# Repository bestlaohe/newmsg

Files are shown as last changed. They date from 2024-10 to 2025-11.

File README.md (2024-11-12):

+--------------------------------+
|                          |     |     <- 电量显示（右上角 16x8）
|                          |     |
|                          |     |
|                          |     |
|                          |     |
|                          |     |
|                          |     |
|       聊天窗口           |     |     <- 聊天窗口（中间 120x100）
|                          |     |
|                          |     |
|                          |     |
|                          |     |
|                          |     |
|                          |     |
|                          |     |
|                          |     |
|                          |     |
|--------------------------|     |
|         输入框           |     |     <- 输入框（底部 120x16）
+--------------------------------+

一格就是一圈来0,1区分正反转，

帮我用***来画一个128*128的tft彩屏的主界面的ui布局，这个界面右上角具有电量显示，中间是聊天窗口，最底下是输入框

聊天窗口交互:

滚轮上滚：切换字母
滚轮下滚：删除一个字母
短按按钮：确认输入的字母
按住并上滚：发送消息
按住并下滚：删除最后一条消息
长按按钮：切换到设置页面

设置页面交互:
滚轮上下滚动：切换设置选项
短按按钮：确认选择的设置
滚轮上下滚动：选择切换的档位
长按按钮：返回聊天窗口

亮度，震动模式，lora频率，发射功率定义，带宽表定义等，还有id设置，

聊天窗口的交互
按住且往上滚表示发送，按住且往下滚表示删除一个，滚动切换字母（一开始为空的），短按按键表示确认，

<!-- 长按按键切换软件交互窗口
聊天记录窗口的交互
滚动翻动聊天记录
按住且往下滚表示删除聊天记录
 -->

长按按键切换设置按钮，短按确认进入设置页面
滚动切换，短按确认，长按返回

限幅动作，找数据超出

休眠独立看门狗复位，按键无法唤醒
都是重新开机，然后看门狗是断开时钟，按键

低速时钟（LSI）
LSI 是系统内部约 128kHz 的 RC 振荡器产生的低速时钟信号。它可以在停机和待机模式下保持
运行，为 RTC 时钟、独立看门狗和唤醒单元提供时钟基准。进一步信息可参考数据手册的电气特性
部分。LSI 可以通过设置 RCC_RSTSCKR 寄存器中的 LSION 位被启动和关闭，然后通过查询 LSIRDY 位
检测 LSI RC 振荡是否稳定，硬件在

看门狗靠这个时钟，把他失能就不会看门狗复位了，现在是唤醒问题，唤醒不了

 4s喂狗，2s唤醒

喂狗必须在while1里面

        开机
        看门狗开
        自动唤醒开
        喂狗
        休眠needsleep==1
        自动唤醒喂狗
        休眠needsleep==1
        自动唤醒喂狗
        休眠needsleep==1
        自动唤醒喂狗
        休眠needsleep==1
        人工唤醒needsleep==0
        自动唤醒喂狗
        人工运行喂狗needsleep==0
        自动唤醒喂狗
        休眠needsleep==1

        while里面判断是否是自动唤醒的状态，是就喂狗，不是跑代码

        if(needsleep==1){
                喂狗+睡觉
        }
        else{
                喂狗+工作

        }

        只刷新一次
        删除信息页面内容

        画矩形太低效了

        聊天记录翻页

           需要验证这个有没有用 Delay_Ms(1);比较耗时3个地方都有

           为什么第一次休眠会乱码

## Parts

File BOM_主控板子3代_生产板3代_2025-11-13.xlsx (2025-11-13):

编号 | 数量 | 备注 | 位号 | 封装 | LCSC Price | LCSC Stock | JLCPCB Price | JLCPCB Stock
1 | 1 | CA-S01 | ANT1 | ANT-SMD_L15.0-W3.0 |  |  | 0.004 | 0 | 完成
2 | 4 | 100nF | C2,C58,C59,C60 | C0603 | 0.0152 | 601410 | 0.0152 | 89490924 | 完成 | 3.16
3 | 1 | 22uF | C4 | C0603 | 0.0575 | 476131 | 0.0575 | 10693591 | 完成 | 2.5
4 | 2 | 1uF | C5,C57 | C0603 | 0.0311 | 112269 | 0.0311 | 11906395 | 完成 | 2
6 | 1 | BAT60B | D8 | SOD-323_L1.7-W1.3-LS2.6-RD-1 | 0.1355 | 1412 | 0.136 | 29969 | 完成 | 5
7 | 1 | AFH34-S12FIA-1H | FPC1 | FPC-SMD_12P-P0.50_THD0509-12CL-GF | 0.8454 | 1512 | 0.845 | 7548 | 完成 | 5
10 | 2 | 1MΩ | R4,R5 | R0603 | 0.0067 | 71383 | 0.0067 | 8524241 | 完成 | 0.81
11 | 2 | 5.1kΩ | R58,R59 | R0603 | 0.0066 | 60036 | 0.0066 | 8171975 | 完成 | 0.81
12 | 1 | 2.2kΩ | R62 | R0603 | 0.0064 | 21609 | 0.0064 | 3307043 | 完成 | 0.81
13 | 1 | 30kΩ | R66 | R0603 | 0.0069 | 19073 | 0.0069 | 2428632 | 完成 | 0.81
14 | 1 | 10kΩ | R67 | R0603 | 0.0067 | 68799 | 0.0067 | 7440441 | 完成 | 0.81
16 | 1 | TM-2024A | SW4 | SW-SMD_TM-2024A | 2.665 | 1312 | 2.665 | 4043 | 完成 | 32.2
17 | 1 | MINI MSK12CO2 | SW5 | SW-SMD_MSK12CO2 | 1.0242 | 27346 | 1.0242 | 110085 | 完成 | 13.9
18 | 1 | CH32V003F4P6 | U1 | OLIMEX_IC-FP:TSSOP20_Pitch-0.65mm_6.6x4.5x1.2mm | 1.7718 | 1229 | 1.772 | 6902 | 完成 | 30
19 | 1 | ME6206A33M3G | U5 | SOT-23-3_L2.9-W1.6-P1.90-LS2.8-BR | 0.3322 | 835 | 0.332 | 9018 | 完成 | 8
20 | 1 | XL1278-SMT | U24 | SX1278 |  |  |  |  | 完成 | 319
21 | 1 | SS8050 | U25 | SOT-23-3_L2.9-W1.3-P1.90-LS2.4-BR | 0.0727 | 10857 | 0.0727 | 546075 | 完成 | 3
22 | 1 | CS-1254R-02 | U29 | CONN-SMD_2P-P1.00_CS-1254R-02 | 0.5538 | 148 | 0.554 | 745 | 完成 | 3.49
23 | 1 | TP4057-42-SOT26-R | U37 | SOT-23-6_L2.9-W1.6-P0.95-LS2.8-BL | 0.8671 | 4162 | 0.867 | 27867 | 完成 | 3.9
25 | 1 | HX TYPE-C 16PIN | USB2 | USB-C-SMD_TYPE-C16PIN | 0.4811 | 4681 | 0.481 | 16437 | 完成 | 7
 |  |  |  |  |  |  |  |  |  | 442.2

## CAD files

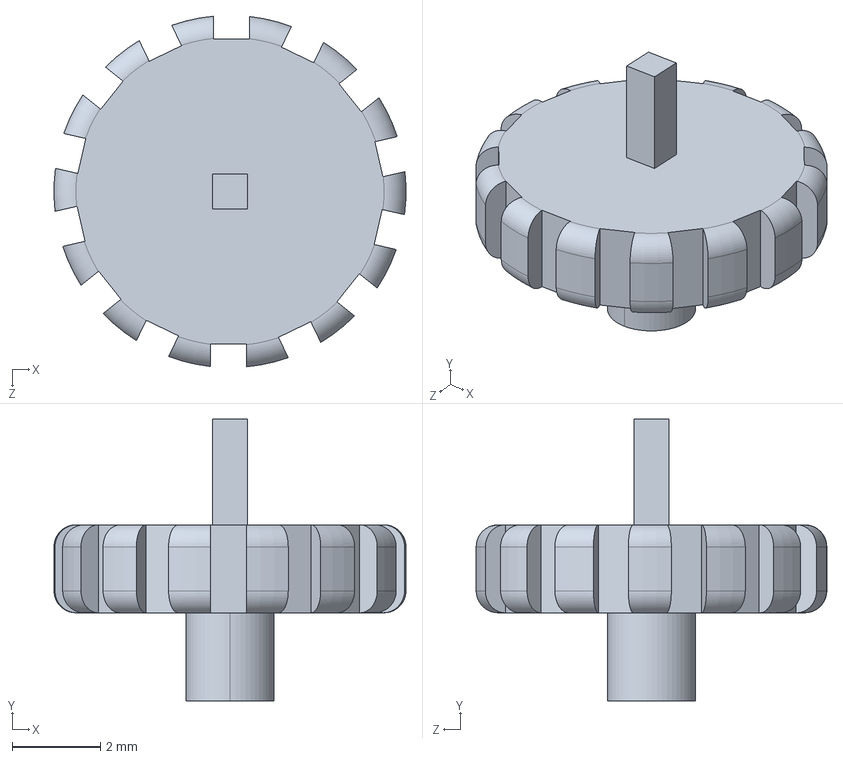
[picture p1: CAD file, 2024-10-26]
结构/滚轮.STEP
8.00 x 6.40 x 7.97 mm

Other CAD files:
结构/滚轮.SLDPRT

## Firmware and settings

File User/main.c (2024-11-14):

#include "debug.h"
#include "encode.h" // timeapp->encode->main
#include "adc.h"    // timeapp->pwm.screen->screen_api->adc->main
#include "SX1278.h" // gpio->SX1278->page
#include "page.h"

// 待机功耗最低，睡眠功耗其次
// 16k=16,384
// data是表示代码段（text segment）的大小，以字节为单位。代码段包含了程序的可执行指令。
// bss是存储那些在源代码中没有显式初始化的全局变量和静态变量。
// data是显式初始化的全局变量和静态变量

//  ROM：
//  text 段：存储程序代码。
//  data 段：存储已初始化的全局变量和静态变量的初始值。

//  RAM：
//  text 段：在运行时用于存储代码执行（不直接占用 RAM 的存储空间，但需要 RAM 来执行）。
//  data 段：在运行时存储已初始化的全局变量和静态变量。
//  bss 段：在运行时存储未初始化的全局变量和静态变量。

// 2+16k

int main(void)
{

  /*********************基本内容初始化******************************/
  SystemCoreClockUpdate(); // 48000000系统时钟刷新3324-3212=100k
  NVIC_PriorityGroupConfig(NVIC_PriorityGroup_1);
  USART_Printf_Init(115200); // 串口初始化需要在打印前，不然会卡死3956-3324=600k
  DEBUG_PRINT("\r\n\r\n\r\n\r\nSystemClk:%d\r\n", SystemCoreClock);
  //  DEBUG_PRINT("ChipID:%08x\r\n", DBGMCU_GetCHIPID());
  Delay_Init(); // 延时初始化需要在延时前，不然会卡死4012-3956=100字节

  // 首次才要
  //  FLASH_Unlock();
  //  FLASH_UserOptionByteConfig(OB_IWDG_SW, OB_STDBY_NoRST, OB_RST_NoEN, OB_PowerON_Start_Mode_BOOT);
  //  FLASH_Lock(); //**4232-4012=200字节

  /*********************应用函数初始化******************************/
  Check_Reset_Flag();                                                // 查询复位原因
  My_GPIO_Init();                                                    // IO口初始化****4484-4232=252字节
  TIM1_Init(100, (SystemCoreClock / (100 * PWM_FRE)) - 1, PWM_Duty); // 屏幕的背光调节  默认百分百亮度******5076-4484=592字节pwm要200多+定时器300
  TIM2_Init(11, 1);                                                  // 编码器的内容,重载值为65535，不分频，1圈12个****6020-6900=880字节输入捕获要500多+定时器300
  LCD_Drive_Init();                                                  // 屏幕硬件初始化****200字节
  LCD_SHOW_API_INIT();                                               // 屏幕测试******8404-6224=2180
  Battery_Init();                                                    // 电池的adc初始化****9456-8636=820
  SX1278_Init();                                                     // lora的初始化*****10268-9620=648
  EXTI_INT_INIT();                                                   // 按键，充电，lora中断初始化
  // startup_animation();                                             // 开机动画
  IWDG_Feed_Init(IWDG_Prescaler_256, 4000); // 该参数必须是介于 0 和 0x0FFF 之间的一个数值    // 4秒不喂狗就复位   低频时钟内部128khz除以256=500，1除以500乘以4000=8s****12467-12356=111字节
  AWU_Init();                               // 唤醒时间为25/12.5大约是2s左右。

  while (1)
  {

    if (needSleep)
    {

      IWDG_ReloadCounter(); // 喂狗
      Sleep_Scan();         // 检查是否睡觉1
    }
    else
    {

      show_page();
      SX1278_Receive();
      Encoder_Scan();
      IWDG_ReloadCounter(); // 喂狗
      Sleep_Scan();         // 检查是否睡觉

      //                             Delay_Ms(1000);
      //                            DEBUG_PRINT("show_page\r\n");
    }
  }
}

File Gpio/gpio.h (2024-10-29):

/*
 * gpio.h
 *
 *  Created on: 2024锟斤拷9锟斤拷1锟斤拷
 *      Author: 12630
 */

#ifndef GPIO_GPIO_H_
#define GPIO_GPIO_H_
#include "ch32v00x_gpio.h"

void My_GPIO_Init();
void My_GPIO_DeInit();
void MOTOR_SET(int state);
#define MOTOR_ON GPIO_ResetBits(GPIOA, GPIO_Pin_2)
#define MOTOR_OFF GPIO_SetBits(GPIOA, GPIO_Pin_2)

#define LCD_CS_ENABLE GPIO_ResetBits(GPIOC, GPIO_Pin_4)
#define LCD_CS_DISABLE GPIO_SetBits(GPIOC, GPIO_Pin_4)

#define LCD_RST_0 GPIO_ResetBits(GPIOD, GPIO_Pin_7)
#define LCD_RST_1 GPIO_SetBits(GPIOD, GPIO_Pin_7)

#define LCD_DC_0 GPIO_ResetBits(GPIOC, GPIO_Pin_2)
#define LCD_DC_1 GPIO_SetBits(GPIOC, GPIO_Pin_2)

#define LCD_SCK_0 GPIO_ResetBits(GPIOC, GPIO_Pin_5)
#define LCD_SCK_1 GPIO_SetBits(GPIOC, GPIO_Pin_5)

#define LCD_SDA_0 GPIO_ResetBits(GPIOC, GPIO_Pin_6)
#define LCD_SDA_1 GPIO_SetBits(GPIOC, GPIO_Pin_6)

#define LCD_BL_0 GPIO_ResetBits(GPIOC, GPIO_Pin_3)
#define LCD_BL_1 GPIO_SetBits(GPIOC, GPIO_Pin_3)

#define SX1278_GPIO GPIOC      // GPIO选择
#define SX1278_NSS GPIO_Pin_0  // 引脚定义
#define SX1278_MOSI GPIO_Pin_6 // 引脚定义
#define SX1278_MISO GPIO_Pin_7 // 引脚定义
#define SX1278_SCK GPIO_Pin_5  // 引脚定义
#define SX1278_RST GPIO_Pin_0  // 复位引脚定义
#define SX1278_NIRQ GPIO_Pin_6 // 引脚定义

#define SX1278_NSS_DISABLE GPIO_SetBits(GPIOD, SX1278_NSS)
#define SX1278_NSS_ENABLE GPIO_ResetBits(GPIOD, SX1278_NSS) // 使能
#define READ_SX1278_MISO() GPIO_ReadInputDataBit(SX1278_GPIO, SX1278_MISO)
#define SET_SX1278_SCK() GPIO_SetBits(SX1278_GPIO, SX1278_SCK)
#define CLR_SX1278_SCK() GPIO_ResetBits(SX1278_GPIO, SX1278_SCK)
#define SET_SX1278_MOSI() GPIO_SetBits(SX1278_GPIO, SX1278_MOSI)
#define CLR_SX1278_MOSI() GPIO_ResetBits(SX1278_GPIO, SX1278_MOSI)
#define SET_SX1278_RST() GPIO_SetBits(SX1278_GPIO, SX1278_RST)       // 复位引脚定义
#define CLR_SX1278_RST() GPIO_ResetBits(SX1278_GPIO, SX1278_RST)     // 用于将 SX1278 模块置于关机模式
#define READ_SX1278_NIRQ() GPIO_ReadInputDataBit(GPIOD, SX1278_NIRQ) // 引脚是 SX1278 模块的中断请求引脚

#define READ_LCD_CS GPIO_ReadOutputDataBit(GPIOC, GPIO_Pin_4)
#define READ_LORA_CS GPIO_ReadOutputDataBit(GPIOD, SX1278_NSS)
#define KEY0 GPIO_ReadInputDataBit(GPIOD, GPIO_Pin_2)
#define CHARGE GPIO_ReadInputDataBit(GPIOC, GPIO_Pin_1)

#endif /* GPIO_GPIO_H_ */

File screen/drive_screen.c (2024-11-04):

/*
 * drive_screen.c
 *
 *  Created on: 2024年8月30日
 *      Author: 12630
 */
#include "drive_screen.h"

/*********************************************************************
 * @fn      SPI_FullDuplex_Init
 *
 * @brief   Configuring the SPI for full-duplex communication.
 *
 * @return  none
 */
void SPI_FullDuplex_Init(void)
{
    SPI_InitTypeDef SPI_InitStructure = {0}; // SPI 初始化结构体

    // 使能 GPIOC 和 SPI1 的时钟
    RCC_APB2PeriphClockCmd(RCC_APB2Periph_SPI1, ENABLE);

    // 配置 SPI 参数
    SPI_InitStructure.SPI_Direction = SPI_Direction_2Lines_FullDuplex; // 设置为全双工模式
    SPI_InitStructure.SPI_Mode = SPI_Mode_Master;                      // 设置为主模式
    SPI_InitStructure.SPI_DataSize = SPI_DataSize_8b;                  // 数据大小设置为 16 位
    SPI_InitStructure.SPI_CPOL = SPI_CPOL_Low;                         // 时钟极性设置为高**************************一开始设置高哦，因为lora所以修改
    SPI_InitStructure.SPI_CPHA = SPI_CPHA_1Edge;                       // 时钟相位设置为第二个边缘*************一开始设置位第二，因为lora所以修改
    SPI_InitStructure.SPI_NSS = SPI_NSS_Soft;                          // NSS 管脚设置为硬件控制
    SPI_InitStructure.SPI_BaudRatePrescaler = SPI_BaudRatePrescaler_4; // 波特率预分频设置为 64
    SPI_InitStructure.SPI_FirstBit = SPI_FirstBit_MSB;                 // 数据位顺序设置为 MSB 优先

    SPI_InitStructure.SPI_CRCPolynomial = 7; // CRC 多项式设置为 7
    SPI_Init(SPI1, &SPI_InitStructure);      // 初始化 SPI1
    SPI_Cmd(SPI1, ENABLE);                   // 使能 SPI1
}

void SPI_DMA_Tx_Init(DMA_Channel_TypeDef *DMA_CHx, u32 ppadr, u32 memadr, u16 bufsize, uint32_t mode, uint32_t MemoryInc)
{
    DMA_InitTypeDef DMA_InitStructure = {0};

    RCC_AHBPeriphClockCmd(RCC_AHBPeriph_DMA1, ENABLE);

    DMA_DeInit(DMA_CHx);

    DMA_InitStructure.DMA_PeripheralBaseAddr = ppadr;
    DMA_InitStructure.DMA_MemoryBaseAddr = memadr;
    DMA_InitStructure.DMA_DIR = DMA_DIR_PeripheralDST;
    DMA_InitStructure.DMA_BufferSize = bufsize;
    DMA_InitStructure.DMA_PeripheralInc = DMA_PeripheralInc_Disable;
    DMA_InitStructure.DMA_MemoryInc = MemoryInc;
    DMA_InitStructure.DMA_PeripheralDataSize = DMA_PeripheralDataSize_Byte;
    DMA_InitStructure.DMA_MemoryDataSize = DMA_MemoryDataSize_Byte;
    DMA_InitStructure.DMA_Mode = mode;
    DMA_InitStructure.DMA_Priority = DMA_Priority_VeryHigh;
    DMA_InitStructure.DMA_M2M = DMA_M2M_Disable;
    DMA_Init(DMA_CHx, &DMA_InitStructure);

    // 使能DMA传输完成中断
    DMA_ITConfig(DMA_CHx, DMA_IT_TC, ENABLE);

    // 配置NVIC
    NVIC_InitTypeDef NVIC_InitStructure;
    NVIC_InitStructure.NVIC_IRQChannel = DMA1_Channel3_IRQn;
    NVIC_InitStructure.NVIC_IRQChannelPreemptionPriority = 0;
    NVIC_InitStructure.NVIC_IRQChannelSubPriority = 0;
    NVIC_InitStructure.NVIC_IRQChannelCmd = ENABLE;
    NVIC_Init(&NVIC_InitStructure);
}

/*
    简易的us级别的延迟函数
    我的芯片时钟是48Mhz
    一个时钟周期是1/48M=0.020833us,一个机器周期包含12个时钟周期，所以一个机器周期是12*0.020833=0.25us
    所以这里i++运行一次是0.25us，1us大概是运行4次
*/
void delay_us(uint16_t num)
{
    for (uint16_t j = 0; j < num; j++)
    {
        for (uint16_t i = 0; i < 2; i++)
        {
        } // 根据不同的芯片周期修改i的数值
    }
}

u8 DEV_SPI_WRite(uint8_t _dat)
{
    while (!READ_LORA_CS)
    {
        DEBUG_PRINT("wait lora cs 1!\r\n");
    }
    u8 retry = 0;
    while (SPI_I2S_GetFlagStatus(SPI1, SPI_I2S_FLAG_TXE) == RESET)
    {
        retry++;
        if (retry > 200)
        {
            DEBUG_PRINT("send spi outtime!\r\n");
            return 0;
        }

    } // 还没发完
    SPI_I2S_SendData(SPI1, (uint16_t)_dat);

    while (SPI_I2S_GetFlagStatus(SPI1, SPI_I2S_FLAG_RXNE) == RESET)
    {
        retry++;
        if (retry > 200)
        {
            DEBUG_PRINT("rec spi outtime!\r\n");
            return 0;
        }
    } // 还没收完

    return (uint8_t)SPI_I2S_ReceiveData(SPI1);
}

int LCD_Drive_Init(void)
{
    SPI_FullDuplex_Init();
    TIM_CtrlPWMOutputs(TIM1, ENABLE);

#if USE_DMA
    SPI_I2S_DMACmd(SPI1, SPI_I2S_DMAReq_Tx, ENABLE); // 启用SPI的DMA发送请求
    DMA_Cmd(DMA1_Channel3, ENABLE);                  // 启用DMA通道
    NVIC_EnableIRQ(DMA1_Channel3_IRQn);              // 启用DMA中断
#endif

    return 0;
}
int LCD_Drive_DeInit(void)
{

    // 禁用 PWM 输出
    TIM_CtrlPWMOutputs(TIM1, DISABLE);
    // 禁用 DMA 通道
#if USE_DMA
    DMA_Cmd(DMA1_Channel3, DISABLE);                  // 禁用DMA通道
    NVIC_DisableIRQ(DMA1_Channel3_IRQn);              // 禁用DMA中断
    SPI_I2S_DMACmd(SPI1, SPI_I2S_DMAReq_Tx, DISABLE); // 禁用SPI的DMA发送请求
#endif
    // 关闭 SPI
    SPI_Cmd(SPI1, DISABLE);                               // 禁用SPI外设
    RCC_APB2PeriphClockCmd(RCC_APB2Periph_SPI1, DISABLE); // 禁用 SPI1 时钟
    return 0;
}

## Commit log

2024-09-01 可以显示屏幕了
2024-09-01 统一gpio口
2024-09-01 加入编码器功能
2024-09-08 添加lora和编码器的功能
2024-09-08 为明天上班做准备
2024-09-09 有消息过来振动一下
2024-09-09 屏幕实时显示电量
2024-09-10 修改命名以及代码结果增加看门狗，4s复位
2024-09-10 编码器内容修改
2024-09-12 添加休眠逻辑，按键读取
2024-09-12 调通蛮多的，编码器还需要调教
2024-09-13 添加了设置logo
2024-09-13 调教好了编码器，增加按键中断，休眠策略
2024-09-14 减少字库大小，电池表，看门狗初始化移动到定时器里面，字库的显示修改
2024-09-14 添加输入捕获中断
2024-09-16 lora可以互相通信了，电量显示，取模显示开机logo完成
2024-09-17 已经修改成dma驱动spi
2024-09-17 开机界面已完成
2024-09-17 做了数字显示电量的适配，
2024-09-18 优化了部分的代码空间
2024-09-19 内存砍到了14200
2024-09-19 按键逻辑设计
2024-09-19 增加电量显示，下一步优化ui，使其进度条通过直线显示
2024-09-20 修复电池问题，按键逻辑
2024-09-20 清空以及历史框框
2024-09-20 添加字母界面逻辑
2024-09-21 在绘图函数中添加边界检查，避免超出显示范围。 - 优化`Paint_DrawLine`中的DMA使用，提高性能。 - 重构`Encoder_Scan`函数，简化编码器位置更新逻辑。 - 修复`KEY_INIT`中的EXTI触发配置，允许上升和下降沿检测。
    此次更改实现了多个增强，包括绘图功能的效率提升、编码器处理的简化以及按键中断配置的正确实施。
    [adc.c, ch32v00x_it.c, encode.c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]
2024-09-22 开发设置更新与Lora通信测试
    - 在.vscode/settings.json中添加了字符串头文件的路径配置。
    - 从Lora/SX1278.c中注释掉Lora测试代码，便于后续正式代码接入。
    - 在Lora/SX1278.h中删除了EXTI6中断初始化函数的声明，并进行相关清理。
    - 在Peripheral/src/ch32v00x_tim.c中注释掉部分TIM配置函数，为简化代码做准备。
    - 在Time/time_app.c中将TIM2的IC初始化改为注释形式，调整代码结构。
    - 在User/ch32v00x_it.c中注释掉DMA中断处理代码，增加了新的DMA循环标志。
2024-09-22 遇到了一个问题，第一个页面会无限制的进行
2024-09-23 功能增强和代码重构
    - 新增`MOTOR_SET`函数，改进了电机控制逻辑。
    - 重构了`Encoder_Scan`函数，优化了编码器扫描流程。
    - 在`main.c`中更新了页面切换逻辑。
    - 在`page.c`中实现了设置页面逻辑，增强了用户界面的功能。
    - 修改了`gpio.c`和`SX1278.c`中的初始化函数，代码更加清晰。
    - 更新了`README.md`，提供了新的功能说明。
    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
2024-09-23 解决了设置页面的新功能的bug
2024-09-23 添加调试信息，回家测试
2024-09-23 发现buf会影响别的地方变量问题
2024-09-24 开始降低内存占用
2024-09-24 优化内存，打印日志变成宏定义控制
2024-09-24 换了一个纯字符的打印函数
2024-09-24 文档更新和调试输出优化
    - 添加了关于字符串、字节和void数据类型的说明到NumPy文档。
    - 调整了用户创建操作中的SQL查询参数顺序，以正确分配UUID。
    - 修改了EntityClass内的重新加载机制，以遵循`flush`参数设置，避免在`flush=false`时刷新新实体。
    - 调整了调试输出，优化了刷新操作的标志和条件检查。
    - 在`Paint_DrawChar`函数中增加了边界检查，并优化了显示小图的DMA操作。
    - 修改了`startup_animation`函数，调整了绘图和清除操作。
    - 重构了`LCD_0IN85_Clear`函数，优化了循环和延迟操作。
    这些更改涉及代码优化、文档改进和修复，旨在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
    [adc.c, ch32v00x_it.c, main.c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]
2024-09-25 硬件优化：电池ADC初始化与DMA配置
    - 优化了电池ADC的初始化过程，现在使用Battery_ADC_Average变量存储平均ADC值。
    - 在DMA配置中，实现了DMA1_Channel1的中断处理，用于处理电池ADC的DMA传输完成事件。
    - 在page.c文件中，更新了info_page函数，使用新的Battery_ADC_Average变量来显示电池信息。
    Note: 这次变更涉及硬件层面的优化，主要在电池ADC初始化和DMA配置上做了调整，以改善电池ADC读取的准确性和效率。
2024-09-26 上班做一下通信隔离
2024-09-27 简化屏幕发送，检查io口，删除没用的使能，修改使能名字
2024-09-27 修复编译bug
2024-09-27 新增12大小的字体
2024-10-17 差解bug
2024-10-22 page移动到函数里面
2024-10-26 适配新的pcba
    [滚轮.SLDPRT, 滚轮.STEP]
2024-10-26 修复lora读取口的bug
2024-10-29 添加充电和休眠策略
2024-10-29 文字互相显示有bug，蓝色跑左边，休眠看门狗似乎没触发，打印重启原因
2024-10-30 添加开机重启日志，增加调试过程
2024-10-30 解决白色主题bug，readme找了两个bug需要解决
2024-10-30 在处理休眠无法唤醒的问题
2024-10-31 试试看看
2024-10-31 解决休眠问题，缺一个看门狗处理。
2024-11-01 添加休眠唤醒逻辑
2024-11-04 调整页面的代码
2024-11-04 休眠调整
2024-11-04 找git的问题
2024-11-04 没啥大问题，把填充搞高效点
2024-11-05 提高刷矩形的效率
2024-11-05 添加了设置页面和滚动查看聊天记录的功能
2024-11-05 需要取模来弄吧。
2024-11-06 添加设置圆球，
2024-11-07 初始化才动，其他操作静态显示
2024-11-07 电池刷新
2024-11-09 准备解决一下充电问题
2024-11-09 进一步处理电量波动问题
2024-11-10 已解决电量波动问题
2024-11-10 优化部分内存
2024-11-12 发现休眠有bug解决了
2024-11-12 解决了变量的bug，调整了休眠宏定义以及debug的宏定义
2024-11-14 修复一点点小bug
2024-11-18 添加报错日志显示
2024-11-20 需要1k内存，取消报错日志显示
2025-11-13 Add files via upload
    boom价格计算
    [BOM_主控板子3代_生产板3代_2025-11-13.xlsx]
